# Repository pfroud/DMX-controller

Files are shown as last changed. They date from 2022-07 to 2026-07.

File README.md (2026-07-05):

# DMX controller

[DMX](https://en.wikipedia.org/wiki/DMX512) is an industry-standard protocol used for controlling stage lighting (and other things). This project is a rudimentary four-channel DMX controller. 

When working at an LED lighting company, I got some lamps from scrap and made some of them work enough to be useful. Those lamps are primarily controlled with DMX.

This project was my first time designing a PCB, and my first time doing 3D printing!!!

<table>
<tr>
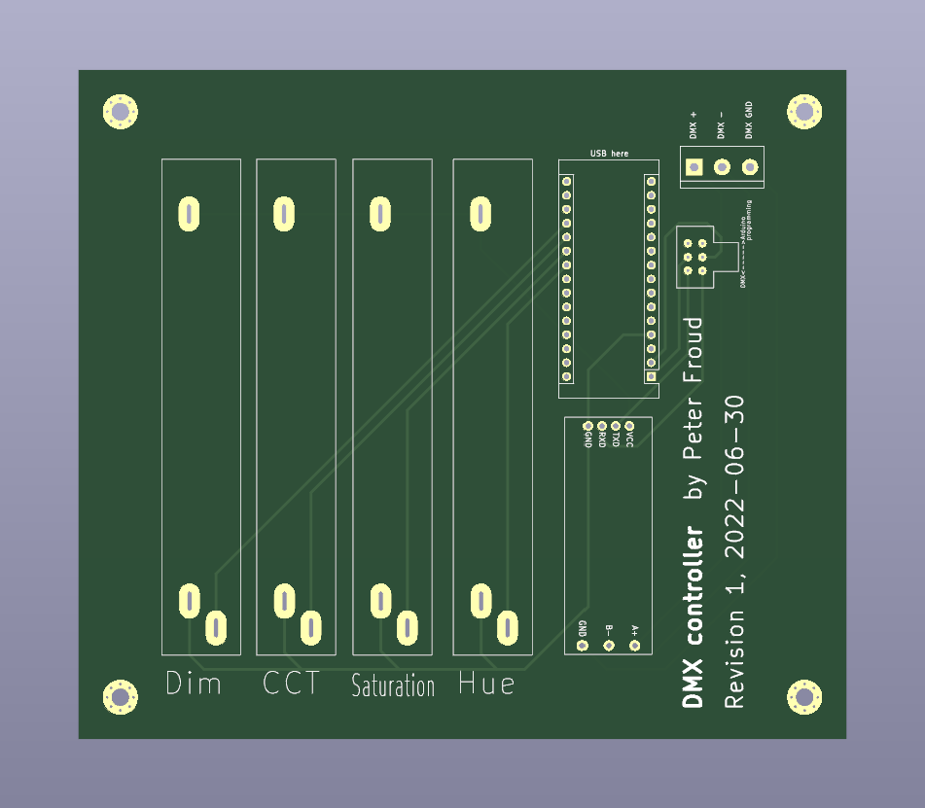
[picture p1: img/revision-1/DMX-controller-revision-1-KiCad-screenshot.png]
Screenshot of DMX controller PCB
<td></td>
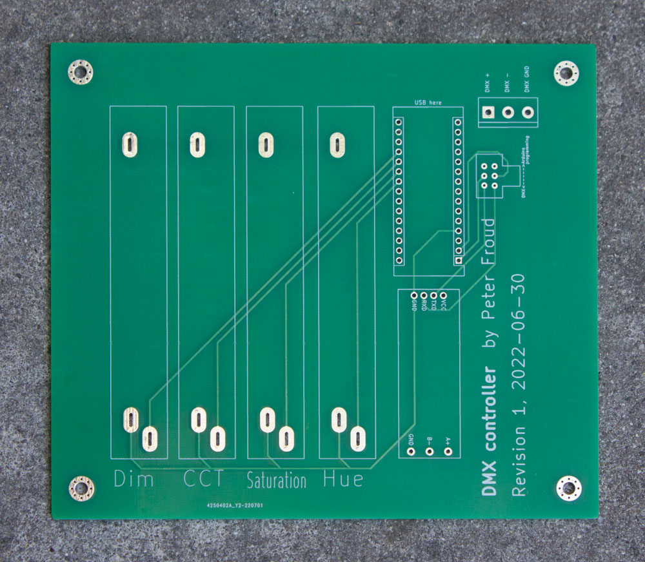
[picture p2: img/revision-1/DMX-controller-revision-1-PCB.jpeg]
Photo of DMX controller PCB
<td></td>
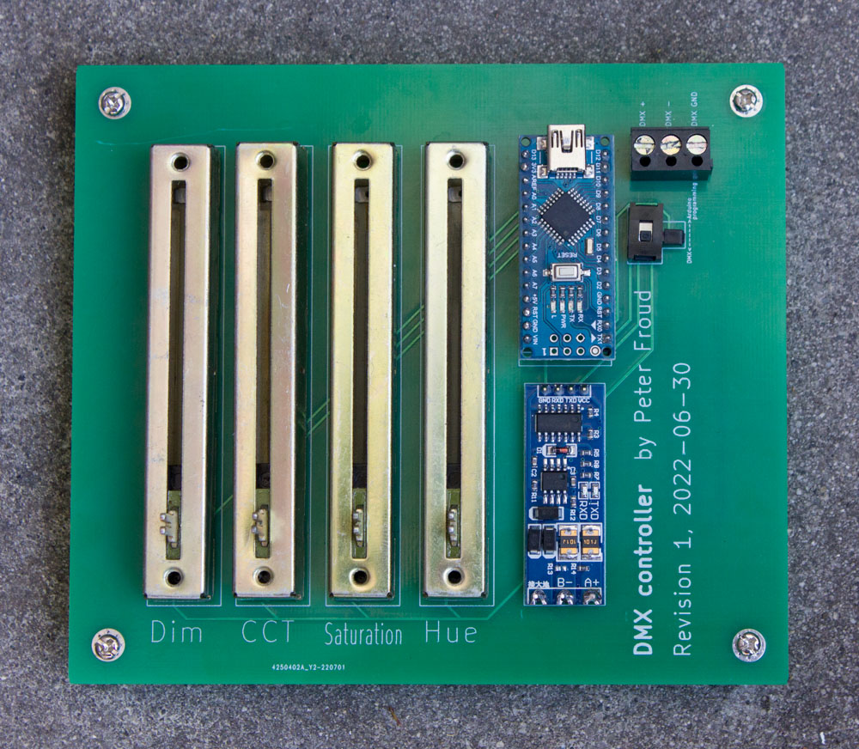
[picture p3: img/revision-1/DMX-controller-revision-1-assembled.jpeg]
Photo of DMX controller assembled
<td></td>
</tr>
</table>

## Parts

* [Arduino Nano](https://en.wikipedia.org/wiki/Arduino_Nano) (not Micro, not Mini)
    * [DMXSerial library by Matthias Hertel](http://www.mathertel.de/Arduino/DMXSerial.aspx)
* Four slide potentiometers
* [TTL-to-RS485 transceiver from AliExpress](https://www.aliexpress.com/item/2251832519311238.html)
* A switch to disconnect the Arduino's RX & TX pins from the RS485 transceiver so the Arduino can be programmed over USB

The PCB was designed using [KiCad](https://www.kicad.org/) version 6 and fabricated by JLCPCB.

## Enclosure

<table>
<tr>
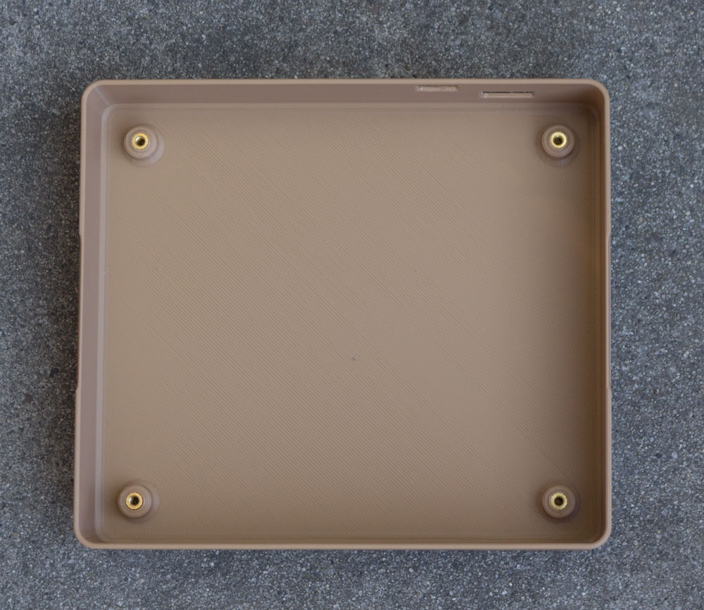
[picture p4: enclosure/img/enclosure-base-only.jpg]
<td></td>
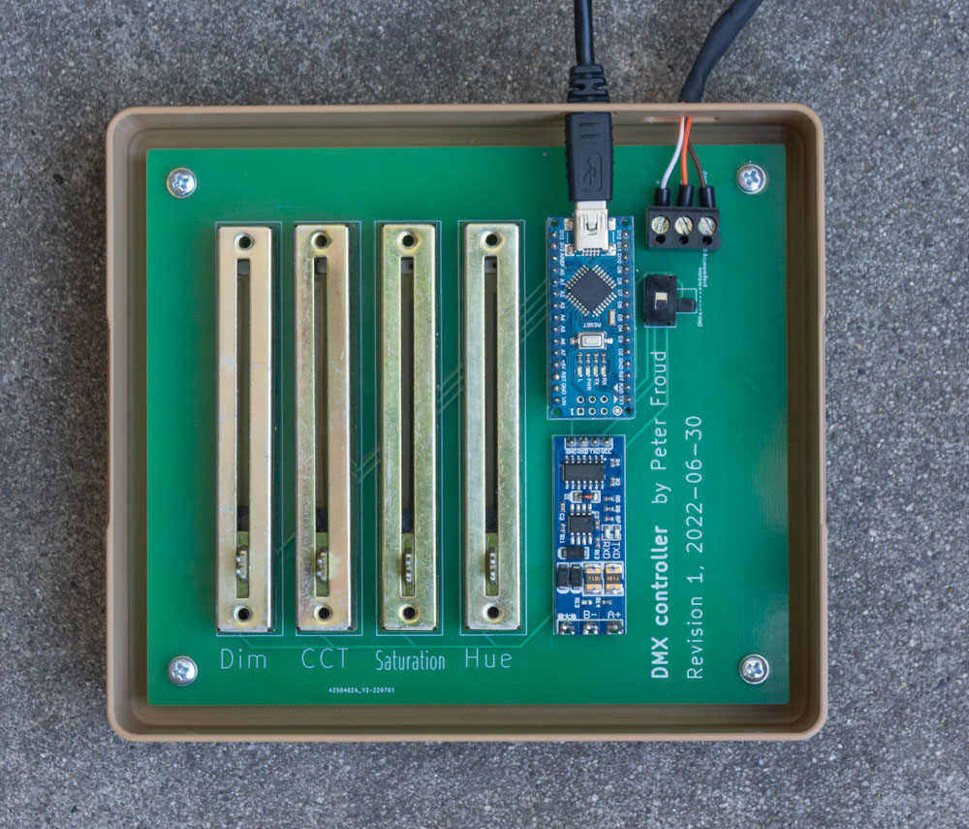
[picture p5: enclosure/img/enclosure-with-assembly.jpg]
<td></td>
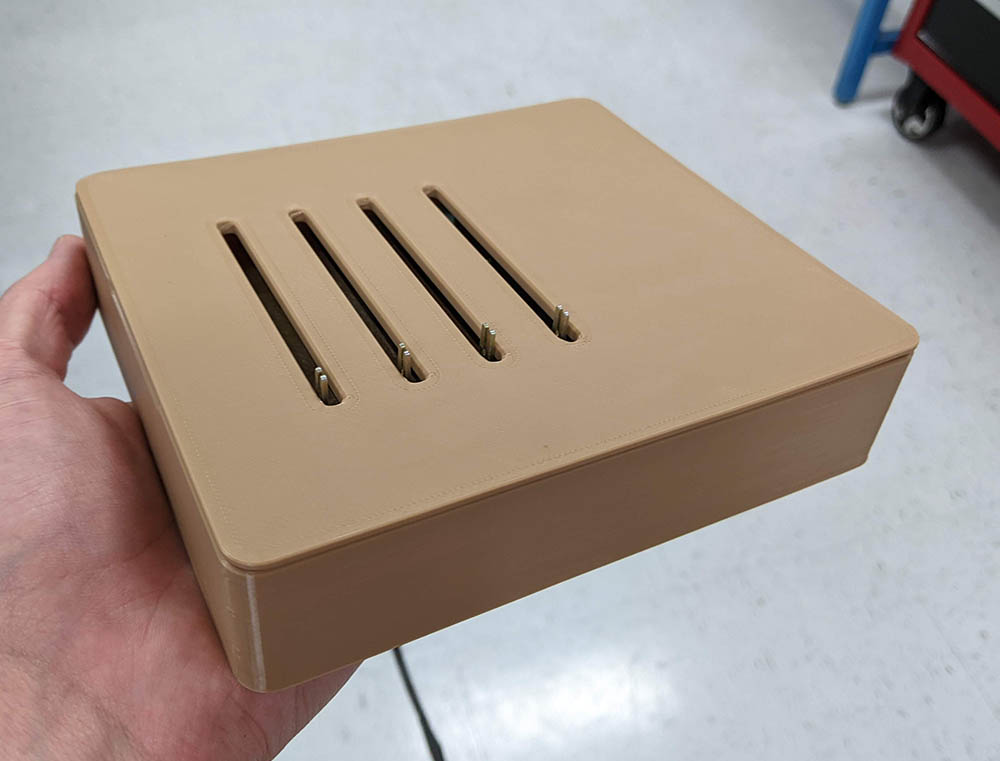
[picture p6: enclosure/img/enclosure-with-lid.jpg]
<td></td>
</tr>
</table>

I used Fusion 360 to design an enclosure to be 3D-printed.

The enclosure is not very good for multiple reasons. It was mostly a test to see if I can make something which fits the board and 3D-prints okay. Happily, my first attempt was successful.

The enclosure was printed on a Creality CR-6 SE using FilaCube PLA 2 filament.

## Prototype

In 2018, I made a prototype DMX controller without a PCB. It was pretty bad but it succeeded as a proof-of-concept.

<table>
<tr>
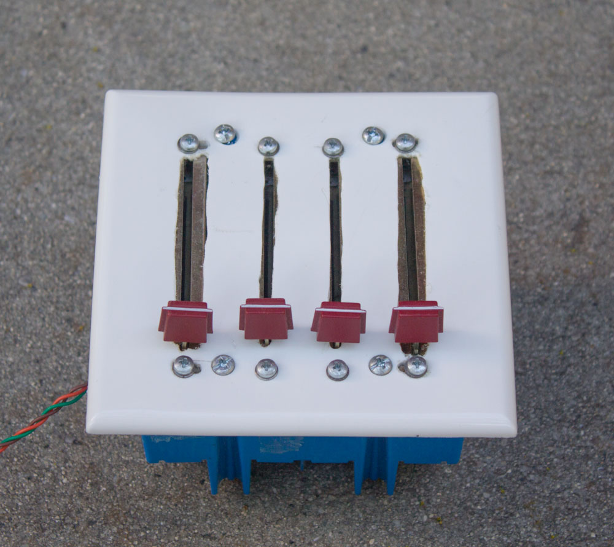
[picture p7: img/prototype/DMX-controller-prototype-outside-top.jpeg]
Top exterior view of DMX controller prototype
<td></td>
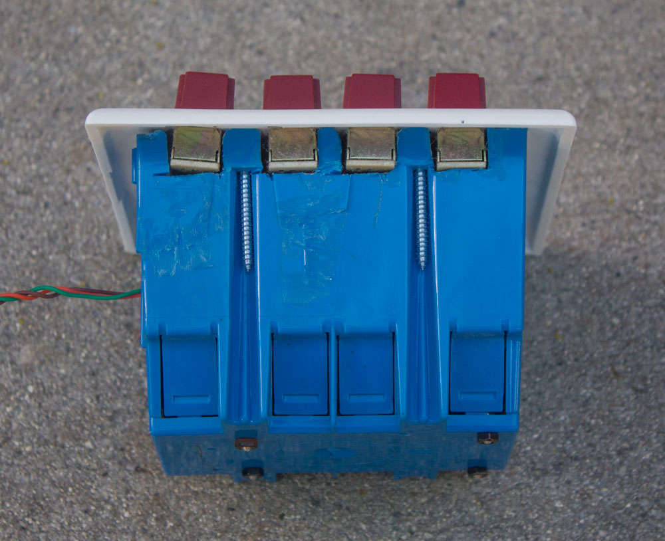
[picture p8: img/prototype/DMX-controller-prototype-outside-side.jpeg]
Side exterior view of DMX controller prototype
<td></td>
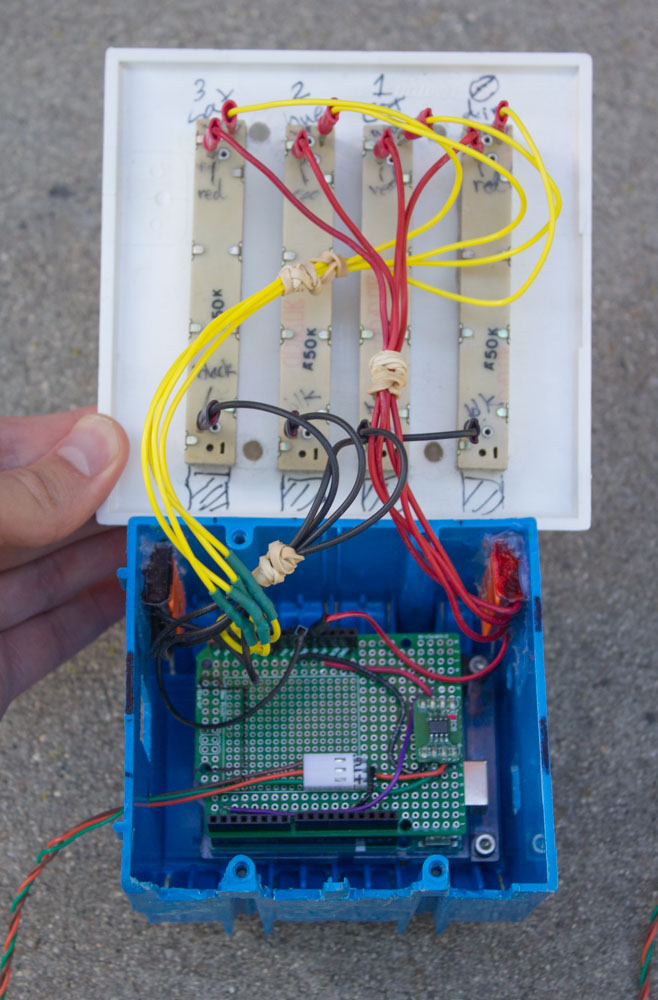
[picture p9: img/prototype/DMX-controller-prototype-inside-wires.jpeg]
Inside view of DMX controller prototype, showing the wires
<td></td>
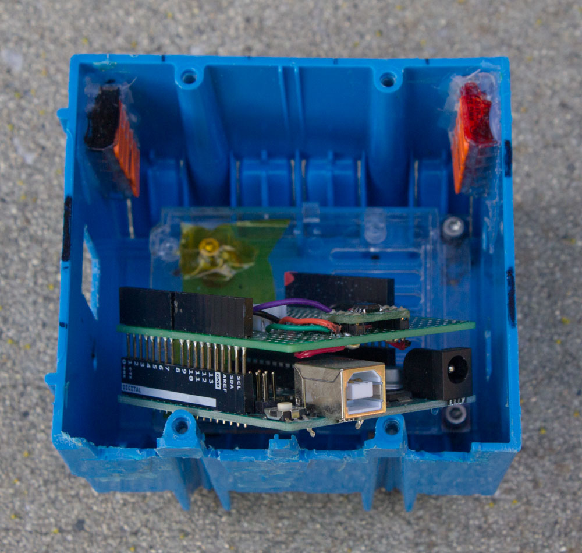
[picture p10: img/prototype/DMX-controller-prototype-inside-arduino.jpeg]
Inside view of DMX controller prototype, showing the Arduino
<td>
</tr>
</table>

The main parts used for the prototype were:

* [Arduino Uno](https://en.wikipedia.org/wiki/Arduino_Uno)
    * [DMXSerial library by Matthias Hertel](http://www.mathertel.de/Arduino/DMXSerial.aspx)
    * Prototype shield 
* [ST1480AC RS-485 transceiver](https://www.st.com/en/interfaces-and-transceivers/st1480ac.html)
* [3-gang electrical outlet box](https://www.homedepot.com/p/100404028)
* [Wago lever-nuts](https://www.wago.com/ca-en/lp-221)
* Three-pin [Molex KK 254](https://www.mattmillman.com/info/crimpconnectors/#kk100) connector

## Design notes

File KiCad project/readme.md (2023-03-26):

# KiCad project

Here's a screenshot of the schematic:

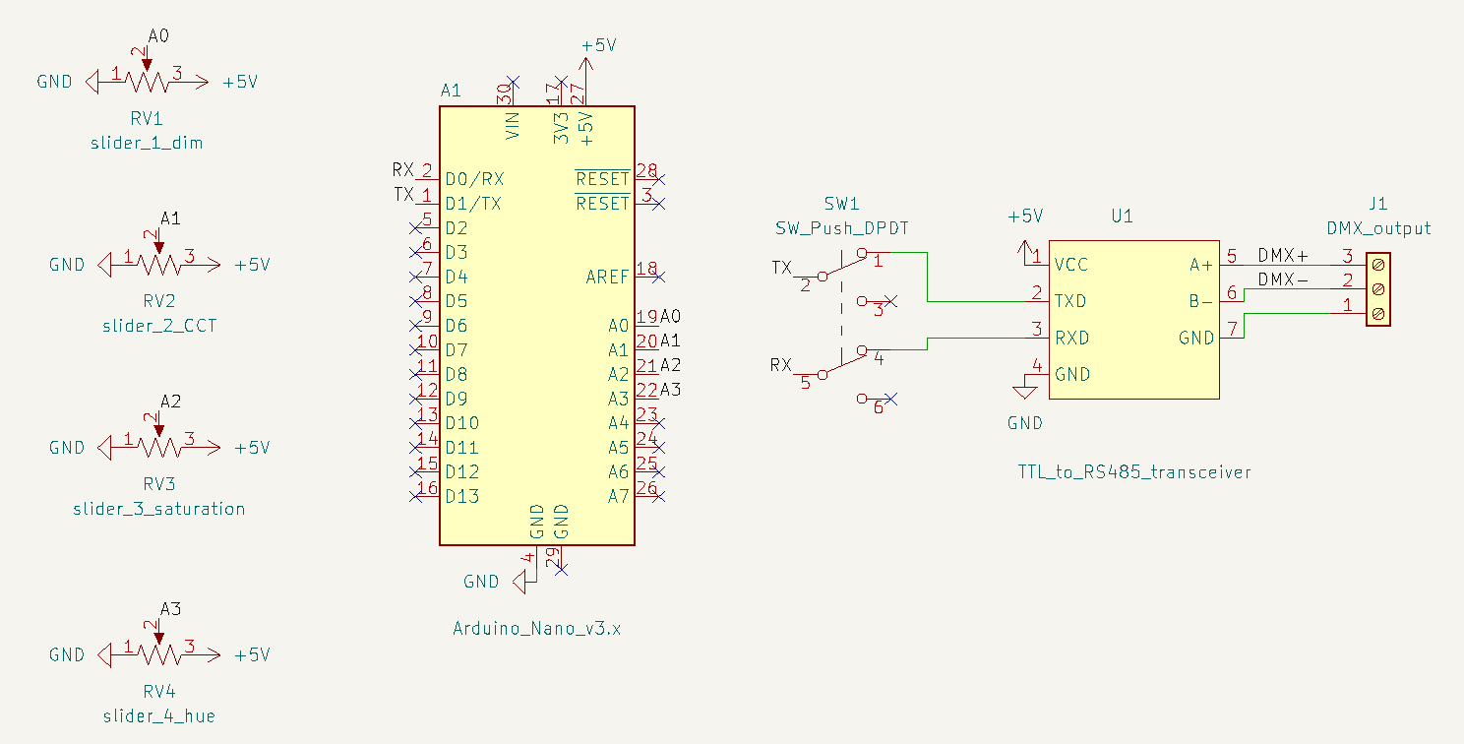
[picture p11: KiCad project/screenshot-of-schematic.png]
Screenshot of DMX controller schematic


There's a DPDT switch is to disconnect the Arduino from the RS485 transceiver. The TX & RX pins must be disconnected form everything otherwise you can't upload sketches.<sup>[[1]](https://forum.arduino.cc/t/cant-upload-code-when-tx-rx-pins-are-connected/341202/4)[[2]](https://arduino.stackexchange.com/a/86)</sup>

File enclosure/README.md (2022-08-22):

# Enclosure for revision 1

## File formats

* `.f3d` is Autodesk Fusion 360 Archive File.
* `.step` is [ISO 10303-21](https://en.wikipedia.org/wiki/ISO_10303-21).
* .`3mf` is [3D Manufacturing Format](https://en.wikipedia.org/wiki/3D_Manufacturing_Format).

## Screenshots

Here's a screenshot from Fusion 360 showing a cross-section of the enclosure:

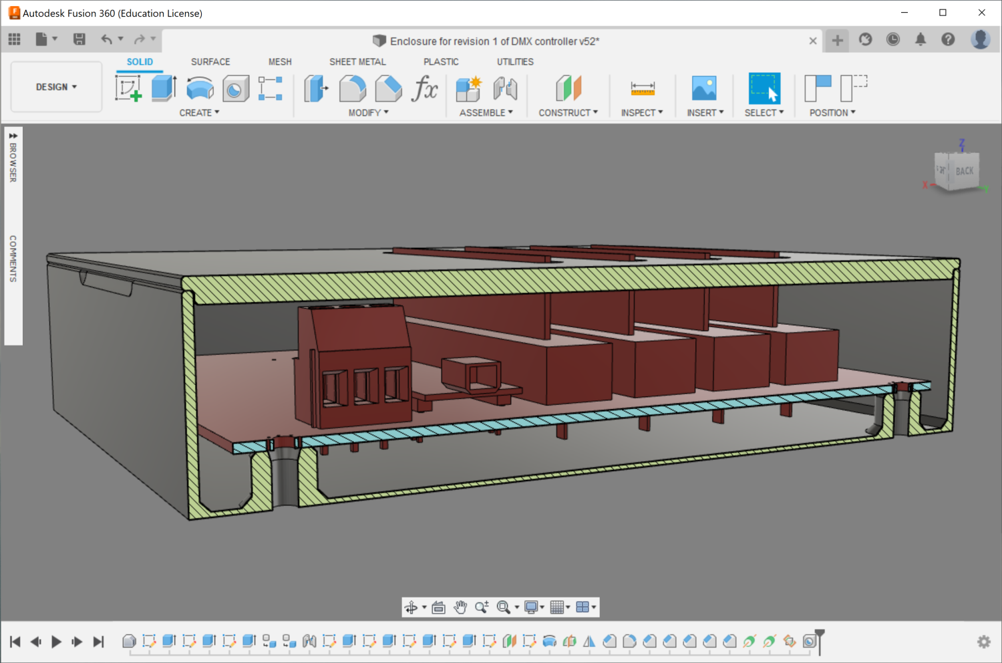
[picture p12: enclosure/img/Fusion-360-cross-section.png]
cross-section view of 3D model in CAD software


I used lots of parameters!

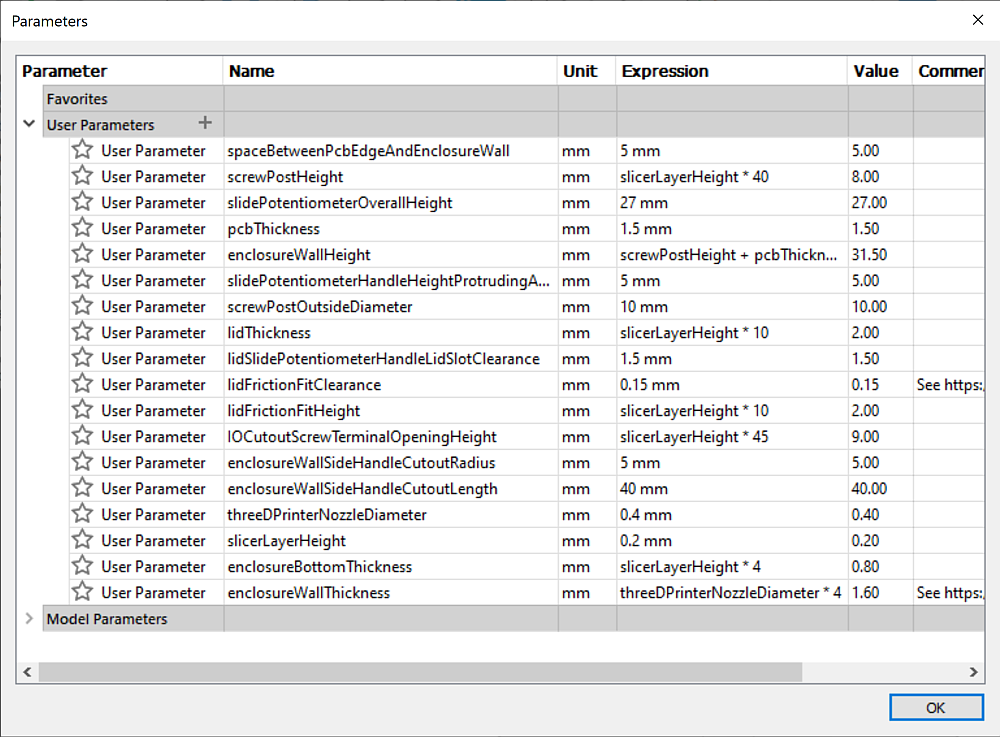
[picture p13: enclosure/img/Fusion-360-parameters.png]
dialog box with a table of numbers


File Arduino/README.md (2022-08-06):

# Arduino folder for DMX controller

## Arduino sketches in this folder

* `read_sliders_and_print_to_serial` - for testing slide potentiometers.
* `send_DMX_from_sliders` - use this for normal operation of the DMX controller.
* `send_random_DMX` - for testing the RS-48s transceiver.

## Instructions 

Once you've installed & launched the Arduino software and connected your Arduino board to your computer:

### Choose processor

Click Tools > Board and choose "Arduino Nano" (not Micro, not Mini.)

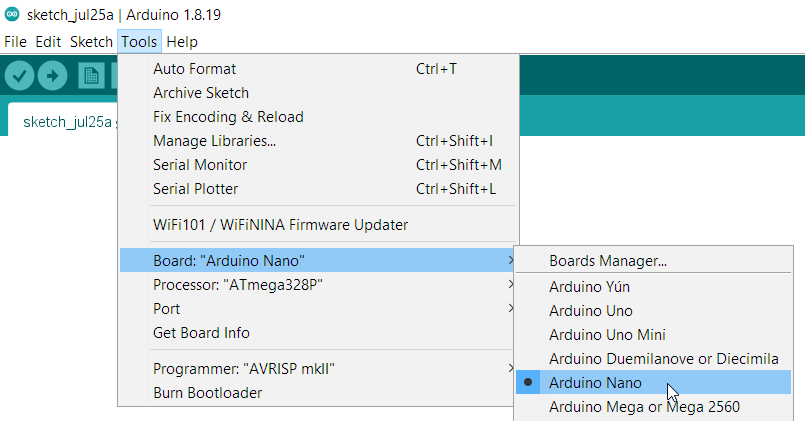
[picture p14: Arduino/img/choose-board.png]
Screenshot of Arduino software, choosing the Arduino Nano board


Once the Arduino Nano board is selected, the Tools menu will have a new sub-menu called Processor:

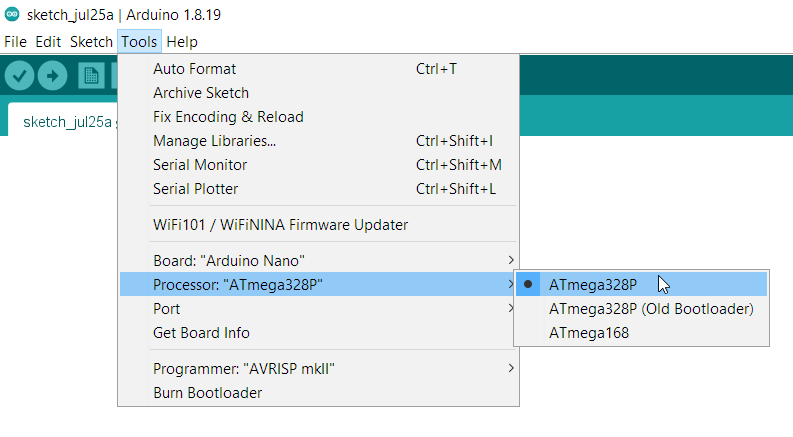
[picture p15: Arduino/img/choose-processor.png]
Screenshot of Arduino software, choosing the Arduino Nano processor


If the processor selected in the Arduino software doesn't match the processor on your board, uploading the sketch won't work.

When it is not working, the horizontal teal bar in the Arduino software which separates the code editor from the console will say "Uploading..." but nothing will happen. You might get an error message like:

```
avrdude: stk500_recv(): programmer is not responding
```
or 
```
avrdude: stk500_getsync() attempt 1 of 10: not in sync: resp=0x00
```
(see the Arduino help page ['Error: avrdude' when uploading](https://support.arduino.cc/hc/en-us/articles/4401874331410--Error-avrdude-when-uploading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).)

When the correct Processor is selected, the upload should finish in a few seconds.

You can just try all three processor options. If the upload is not working, unplug the USB cable connecting the Arduino board to your computer and the upload process wil immediately stop.

If you want to check which processor is on your board, look at the big black square chip mounted at a 45-degree angle on the top of the Arduino Nano. It will either say "MEGA328" or "MEGA168". You will need magnification, and you will need to tilt the board to get good lighting.

<table>
<tr>
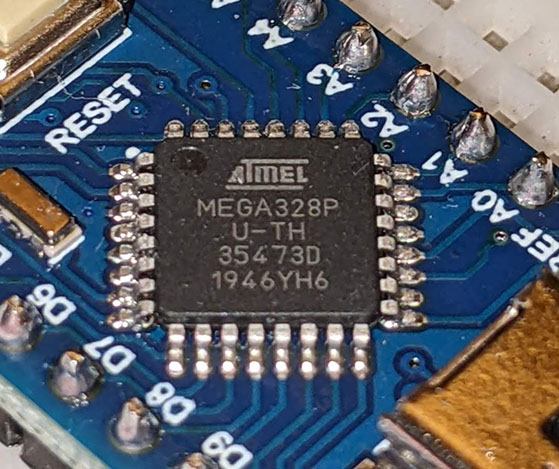
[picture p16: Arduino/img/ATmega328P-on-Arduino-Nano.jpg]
ATmega328P microcontroller on Arduino Nano
<td></td>
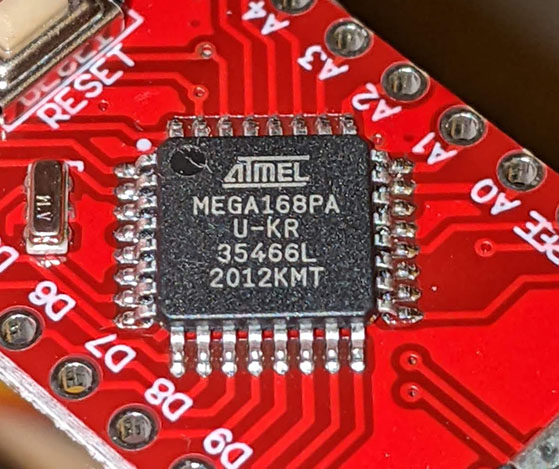
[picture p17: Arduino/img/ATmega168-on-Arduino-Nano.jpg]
ATmega160 microcontroller on Arduino Nano
<td></td>
</tr>
</table>

if the chip says 328, you have to try the both the "ATmega328P" and "ATmega328P (Old Bootloader)" processor options.

### Install libraries

1. Click Tools > Manage Libraries.

1. Install the DMXSerial library:

    Screenshot of DMXSerial library in Arduino Library Manager

   Links to documentation:

   * https://www.arduino.cc/reference/en/libraries/dmxserial/
   * https://github.com/mathertel/DmxSerial

1. Install the TimerOne library:

    Screenshot of TimerOne library in Arduino Library Manager

    Link to documentation: 

    * https://www.arduino.cc/reference/en/libraries/timerone/

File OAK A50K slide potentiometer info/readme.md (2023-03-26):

# Slide potentiometer info

I got the slide potentiometers from HSC Electronics in 2018. The only marking on them is "OAK A50K".

They have a logarithmic resistance curve (intended for audio applications) which is not actually what we want for a DMX controller.

To commemorate the closing of HSC, I am including this photo of the original box with the price:

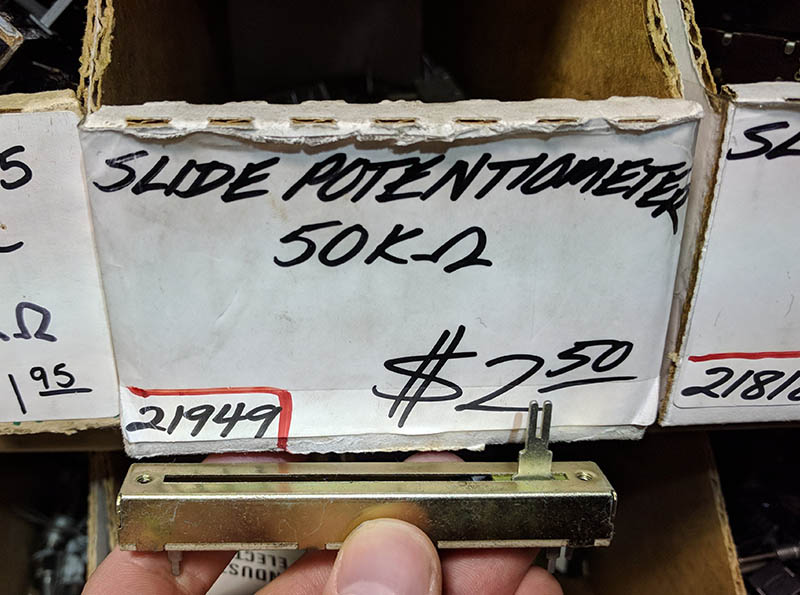
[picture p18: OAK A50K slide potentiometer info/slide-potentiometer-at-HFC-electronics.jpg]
photo of slide potentiometer


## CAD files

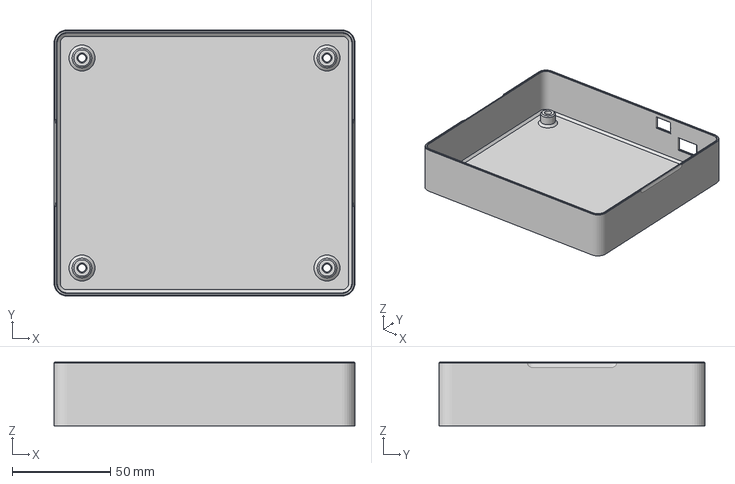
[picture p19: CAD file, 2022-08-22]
enclosure/Enclosure for revision 1 of DMX controller v52 - base.3mf
152.9 x 135.1 x 32.3 mm

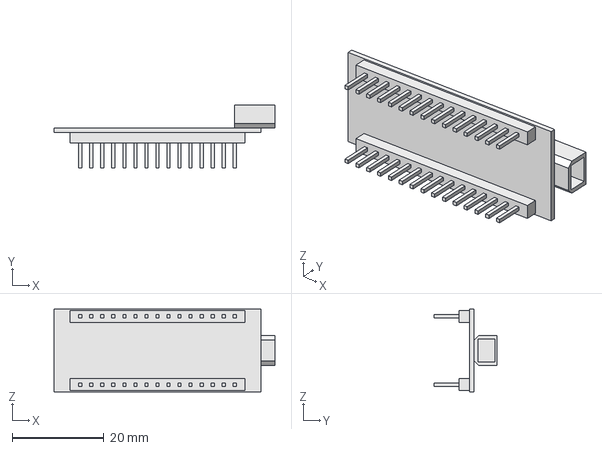
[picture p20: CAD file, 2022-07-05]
KiCad project/3D models/Arduino Nano simplified.step
48.0 x 13.8 x 18.0 mm

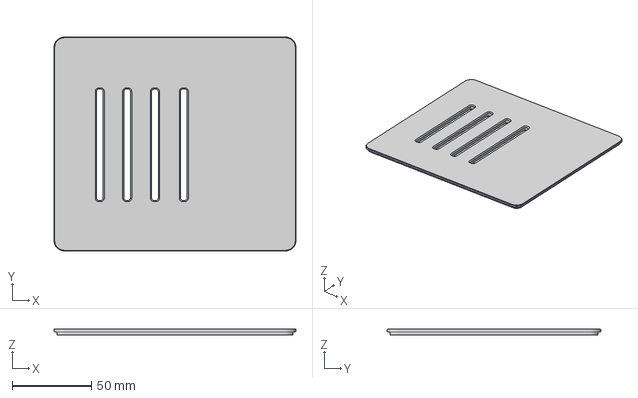
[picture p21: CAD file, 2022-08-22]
enclosure/Enclosure for revision 1 of DMX controller v52 - lid.3mf
152.9 x 135.1 x 4.00 mm

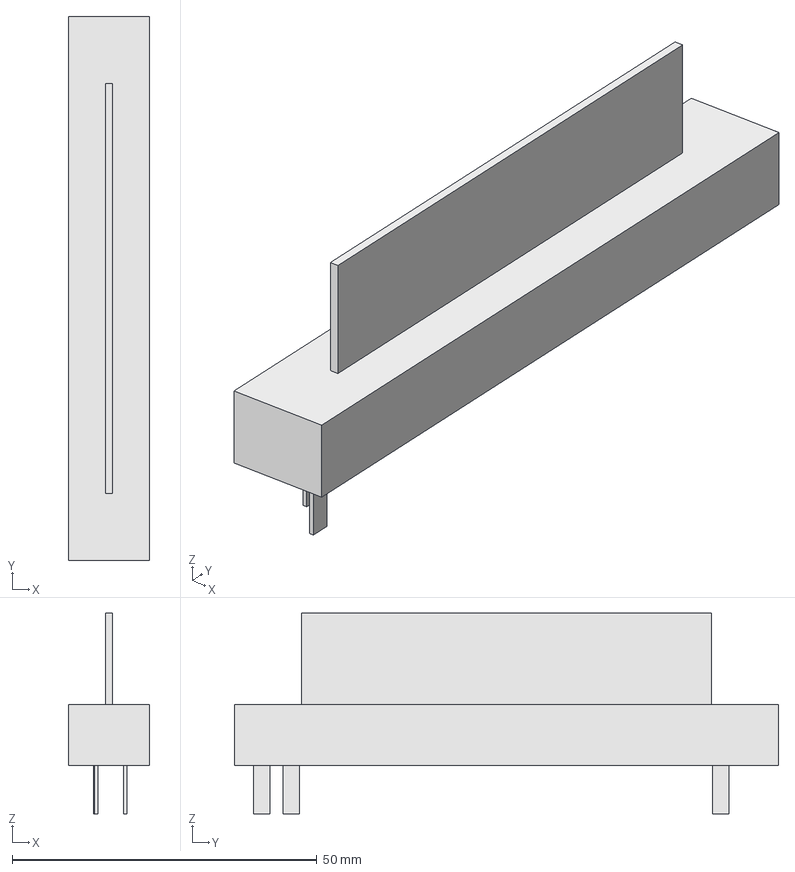
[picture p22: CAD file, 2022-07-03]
KiCad project/3D models/OAK A50K slide potentiometer.step
13.4 x 89.3 x 33.0 mm

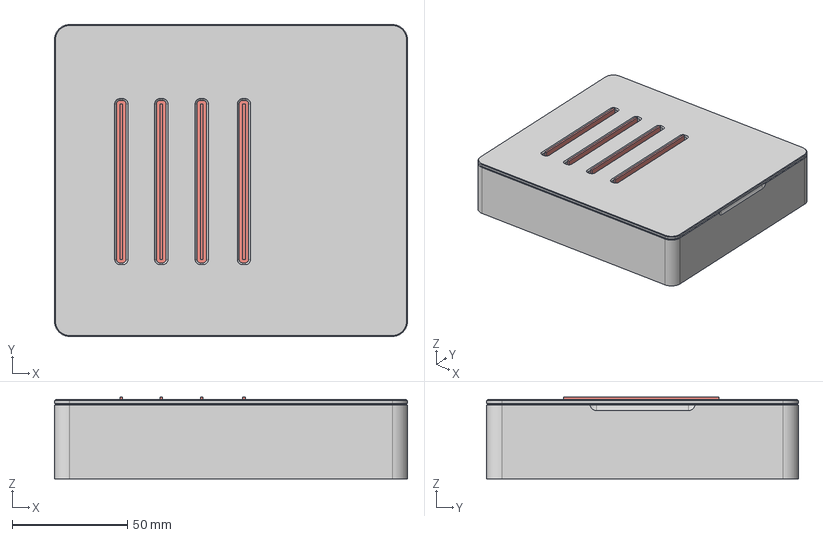
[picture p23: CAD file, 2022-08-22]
enclosure/Enclosure for revision 1 of DMX controller v52.step
152.9 x 135.1 x 35.4 mm
PCB with parts
enclosure

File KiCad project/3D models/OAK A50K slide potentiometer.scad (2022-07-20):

// unit = millimeter

bodySizeX = 13.38;
bodySizeY = 89.34;
bodySizeZ = 10;

//invert Y axis to match KiCad coordinate system
scale([1, -1, 1]){
    union(){

        //body
        cube([bodySizeX, bodySizeY, bodySizeZ]);

        // pins
        pinSizeX = 0.57;
        pinSizeY = 2.68;
        pinSizeZ = 8;
        translate([4.18, 8.14, -pinSizeZ]) {
            cube([pinSizeX, pinSizeY, pinSizeZ]);
        }

        translate([4.28, 78.66, -pinSizeZ]) {
            cube([pinSizeX, pinSizeY, pinSizeZ]);
        }

        translate([9.1, 83.53, -pinSizeZ]) {
            cube([pinSizeX, pinSizeY, pinSizeZ]);
        }

        // handle
        handleSizeX = 1.16;
        handleYDistanceFromEdge = 11;
        handleSizeY = (bodySizeY - (handleYDistanceFromEdge*2));
        handleSizeZ = 15;
        translate([
                (bodySizeX-handleSizeX)/2,
                (bodySizeY-handleSizeY)/2,
                bodySizeZ
            ]){
            cube([handleSizeX, handleSizeY, handleSizeZ]);
        }
    }
}

/*
Copyright Peter Froud 2022.

This source describes Open Hardware
and is licensed under the CERN-OHL-S v2.

You may redistribute and modify this
source and make products using it under
the terms of the CERN-OHL-S v2
(https://ohwr.org/cern_ohl_s_v2.txt).

This source is distributed WITHOUT ANY
EXPRESS OR IMPLIED WARRANTY,
INCLUDING OF MERCHANTABILITY,
SATISFACTORY QUALITY AND FITNESS FOR A
PARTICULAR PURPOSE. Please see the
CERN-OHL-S v2 for applicable conditions. 

Source location: 
https://github.com/pfroud/DMX-controller
*/

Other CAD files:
enclosure/Enclosure for revision 1 of DMX controller v52.f3d

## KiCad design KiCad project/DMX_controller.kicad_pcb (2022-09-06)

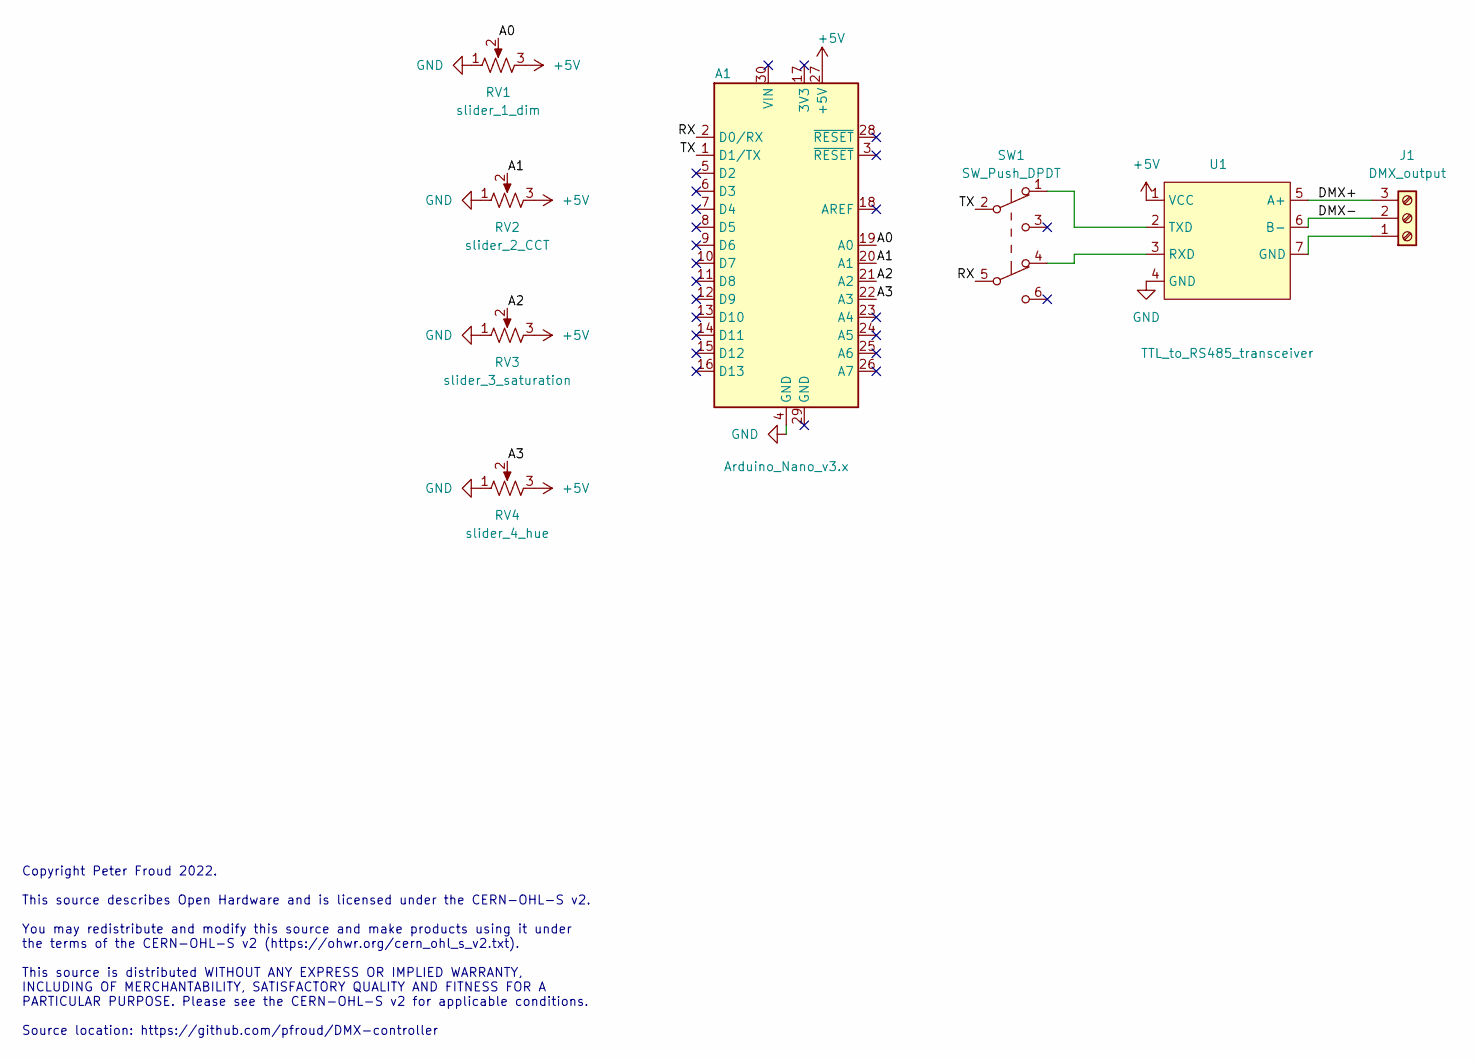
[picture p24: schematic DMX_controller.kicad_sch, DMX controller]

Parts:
A1: Arduino_Nano_v3.x; Arduino_Nano
J1: DMX_output; TerminalBlock_Phoenix_MKDS-3-3-5.08_1x03_P5.08mm_Horizontal
RV1: slider_1_dim; slide_potentiometer_OAK_A50K
RV2: slider_2_CCT; slide_potentiometer_OAK_A50K
RV3: slider_3_saturation; slide_potentiometer_OAK_A50K
RV4: slider_4_hue; slide_potentiometer_OAK_A50K
SW1: SW_Push_DPDT; slide_switch_DPDT_black_plastic_red_sealed_terminals
U1: TTL_to_RS485_transceiver

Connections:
+5V: A1.27 (+5V), RV1.3, RV2.3, RV3.3, RV4.3, U1.1 (VCC)
/A0: A1.19 (A0), RV1.2
/A1: A1.20 (A1), RV2.2
/A2: A1.21 (A2), RV3.2
/A3: A1.22 (A3), RV4.2
/DMX+: J1.3, U1.5 (A+)
/DMX-: J1.2, U1.6 (B-)
/RX: A1.2 (D0/RX), SW1.5 (B)
/TX: A1.1 (D1/TX), SW1.2 (B)
GND: A1.4 (GND), RV1.1, RV2.1, RV3.1, RV4.1, U1.4 (GND)
unnamed: J1.1, U1.7 (GND)
unnamed: SW1.1 (A), U1.2 (TXD)
unnamed: SW1.4 (A), U1.3 (RXD)

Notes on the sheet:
Copyright Peter Froud 2022. This source describes Open Hardware and is licensed under the CERN-OHL-S v2. You may redistribute and modify this source and make products using it under the terms of the CERN-OHL-S v2 (https://ohwr.org/cern_ohl_s_v2.txt). This source is distributed WITHOUT ANY EXPRESS O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

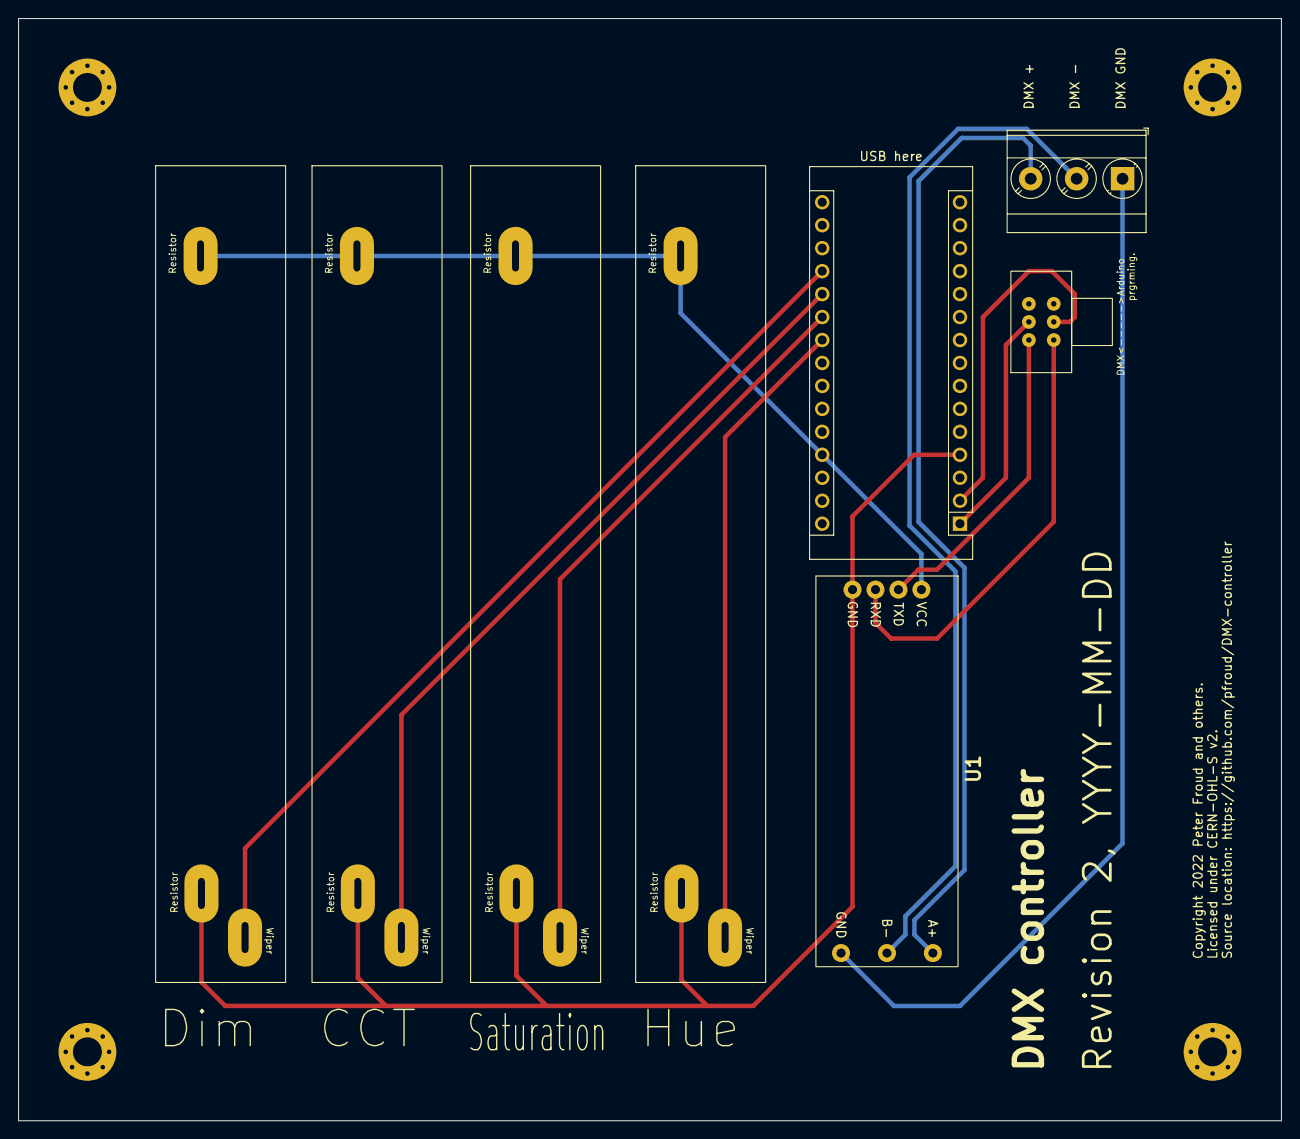
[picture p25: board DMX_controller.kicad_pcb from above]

Board: 2 copper layers, 139.7 x 121.9 mm, 12 parts (0 on the bottom side), 13 nets.

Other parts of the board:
MH1, MH2, MH3, MH4: MountingHole_3.2mm_M3_Pad_Via

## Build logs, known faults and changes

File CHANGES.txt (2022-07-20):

Anyone modifying the design should provide brief information about
the modifications, including the date they were made. Information
about the design should be added but never removed from this file.
See section 3.3.b of the license.

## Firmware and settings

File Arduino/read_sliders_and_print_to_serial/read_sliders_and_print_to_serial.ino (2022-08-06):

/*
You can use this Arduino sketch to test your slide potentiometers.
*/

void setup() {
  Serial.begin(9600);
}

void loop() {
  Serial.print(analogRead(A0));
  Serial.print(", ");
  Serial.print(analogRead(A1));
  Serial.print(", ");
  Serial.print(analogRead(A2));
  Serial.print(", ");
  Serial.println(analogRead(A3));
  delay(100);
}

/*
Copyright Peter Froud 2022.

This source describes Open Hardware and is licensed under the CERN-OHL-S v2.

You may redistribute and modify this source and make products using it under
the terms of the CERN-OHL-S v2 (https://ohwr.org/cern_ohl_s_v2.txt).

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
Source location: https://github.com/pfroud/DMX-controller
*/

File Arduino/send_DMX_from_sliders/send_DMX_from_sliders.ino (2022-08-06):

#include <TimerOne.h>
#include <DMXSerial.h>

// DMX is eight-bit, so the maximum value is 2^8 - 1.
#define DMX_MAXIMUM 255
#define DMX_MINIMUM 0

/*
The Arduino has a ten-bit analog-to-digital converter,
so the maximum value is 2^10 - 1.
https://www.arduino.cc/reference/en/language/functions/analog-io/analogread/
*/
#define ARDUINO_ADC_MAXIMUM 1023
#define ARDUINO_ADC_MINIMUM 0



void setup() {
  /*
  The parameter is from the enum DMXMode from DMXSerial.h, but apparently we don't specify the enum name.
  
  Documentation about the DMXSerial.init() function:
  https://www.mathertel.de/Arduino/DMXSerial/api/class_d_m_x_serial_class.htm#adf6e7c30360e49fec3c458dc7e557f90
  
  The declaration of the DMXMode enum:
  https://github.com/mathertel/DMXSerial/blob/59393dfc5629c04447e23748ad6f62887482de87/src/DMXSerial.h#L56
  */
  DMXSerial.init(DMXController);

  /*
  The unit is microseconds. 1 microsecond = 1e-6 sec = 1 /(1,000,000) sec.
  
  1e5 microseconds = 100,000 microseconds = 100 milliseconds = 0.1 seconds -> 10 Hz.
  
  The data rate of DMX is 250 kbit/sec which means 250 kHz.
  
  https://www.pjrc.com/teensy/td_libs_TimerOne.html
  */
  Timer1.initialize(1e5);
  Timer1.attachInterrupt(timerInterruptServiceRoutine);
}

void timerInterruptServiceRoutine() {
  /*
  The first DMX channel is one not zero.
  
  Docs about the DMX library:
  http://www.mathertel.de/Arduino/DMXSerial.aspx
  
  Documentation about the DMXSerial.write() function:
  http://www.mathertel.de/Arduino/DMXSerial/api/class_d_m_x_serial_class.htm#a7bded1ed6237d6a113d1f1cc4a7785a1
  
  Documentation about the Arduino map() function:
  https://www.arduino.cc/reference/en/language/functions/math/map/
  */
  DMXSerial.write(1, map(analogRead(A0), ARDUINO_ADC_MINIMUM, ARDUINO_ADC_MAXIMUM, DMX_MINIMUM, DMX_MAXIMUM));
  DMXSerial.write(2, map(analogRead(A1), ARDUINO_ADC_MINIMUM, ARDUINO_ADC_MAXIMUM, DMX_MINIMUM, DMX_MAXIMUM));
  DMXSerial.write(3, map(analogRead(A2), ARDUINO_ADC_MINIMUM, ARDUINO_ADC_MAXIMUM, DMX_MINIMUM, DMX_MAXIMUM));
  DMXSerial.write(4, map(analogRead(A3), ARDUINO_ADC_MINIMUM, ARDUINO_ADC_MAXIMUM, DMX_MINIMUM, DMX_MAXIMUM));
}

void loop() {
    // nothing
}

/*
Copyright Peter Froud 2022.

This source describes Open Hardware and is licensed under the CERN-OHL-S v2.

You may redistribute and modify this source and make products using it under
the terms of the CERN-OHL-S v2 (https://ohwr.org/cern_ohl_s_v2.txt).

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
Source location: https://github.com/pfroud/DMX-controller
*/

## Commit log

2022-06-27 Move KiCad project to subdirectory
    [DMX_controller.kicad_pcb, DMX_controller.kicad_sch]
2022-06-27 Add Arduino sketches
2022-06-28 Clean up 485 transceiver footprint+schematic
2022-06-28 Clean up schematic
    [DMX_controller.kicad_sch]
2022-06-29 Make a real PCB!
    [DMX_controller.kicad_pcb]
2022-06-29 Correct slide potentiometer pin numbering
    [DMX_controller.kicad_pcb, DMX_controller.kicad_sch]
2022-06-29 Add reference material for slide potentiometer
    [Footprint coordinates.ods, OAK A50K slide potentiometer coordinates.ods, Resistance curve.ods]
2022-06-30 Increase track width from 0.25mm to 0.5mm
    [DMX_controller.kicad_pcb]
2022-06-30 Set date stamp for revision 1
    [DMX_controller.kicad_pcb]
2022-06-30 Add pads and vias to mounting holes
    [DMX_controller.kicad_pcb]
2022-07-03 Rotate screw terminal so 3D model is oriented
    [DMX_controller.kicad_pcb, DMX_controller.kicad_sch]
2022-07-03 Commit Gerber settings for JLCPCB
    [DMX_controller.kicad_pcb]
2022-07-03 Add 3D models to slide pot and screw terminal
    [DMX_controller.kicad_pcb, DMX_controller.kicad_sch, OAK A50K slide potentiometer.scad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]
2022-07-03 Add 3D model for Arduino Nano
    [DMX_controller.kicad_pcb]
2022-07-05 Set grid origin to use FreeCAD KiCadStepUp plugin
    [DMX_controller.kicad_pcb]
2022-07-05 Change Arduino Nano 3D model from x3d to step so FreeCAD can load it using KiCadStepUp plugin
    By Ahmed Abdelftah on GrabCAD
    https://grabcad.com/library/arduino-nano-case-3d-printed-1
    [Arduino Nano simplified.step, DMX_controller.kicad_pcb]
2022-07-20 Route DMX (RS-485) as differential pair
    [DMX_controller.kicad_pcb, DMX_controller.kicad_sch]
2022-07-20 Add CERN Open Hardware License Strongly Reciprocal
    [DMX_controller.kicad_pcb, DMX_controller.kicad_sch, Footprint coordinates.ods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]
2022-07-20 Add KiCad screenshot
2022-07-20 Add note that I modified the Arduino Nano 3D model
2022-08-06 Add info about prototype
2022-08-06 Add documentation about Arduino sketches
2022-08-19 Move footprint pin 1 to 0,0
2022-08-22 Add info about 3D-printed enclosure
    [Enclosure for revision 1 of DMX controller v52 - base.3mf, Enclosure for revision 1 of DMX controller v52 - lid.3mf, Enclosure for revision 1 of DMX controller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]
2022-09-06 Fix slide switch pads and fab
    The pitch is 2.00mm in the X direction and 2.75mm in the Y direction
2022-09-06 Fix silkscreen
2022-09-06 Update PCB
    [DMX_controller.kicad_pcb]
2022-09-06 Ignore folder of gerbers
2022-09-06 Fix TTL-to-RS485 transceiver footprint pin spacing
2022-09-06 Update silkscreen and courtyard
2022-12-26 Clarify modifications to Arduino Nano 3D model
2023-03-26 Add readme for Kicad project

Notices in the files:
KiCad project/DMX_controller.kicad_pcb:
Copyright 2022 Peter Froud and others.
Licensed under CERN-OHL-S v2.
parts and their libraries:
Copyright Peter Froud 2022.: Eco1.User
